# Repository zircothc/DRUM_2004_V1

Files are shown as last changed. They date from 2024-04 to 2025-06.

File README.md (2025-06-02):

# DRUM_2024_V1

ESP32 DRUM SYNTH MACHINE

This is my DRUM SYNTH LOFI MACHINE.



# Synth engine:

- Wavetable synthesizer based on DZL Arduino library ["The Synth"](https://github.com/dzlonline/the_synth)
- 16 sound polyphony
- Sound parameters: Table, Length, Envelope, Pitch, Modulation, + Volume, Pan and Filter.
- Filter (LowPassFilter) comes from [Mozzi Library](https://github.com/sensorium/Mozzi)

SEQUENCER:

- 16 step/pattern editor and random generators (pattern, sound parameters and notes)

# Hardware:

- Lolin S2 Mini (ESP32 S2)
- PCM5102A I2s dac
- 24 push buttons (8x3)
- Rotary encoder
- OLED display I2c
- 32 LED WS2812B

# Software:

IDE:
Arduino `1.8.19` 
Arduino `2.3.2`

Boards:
Expressif Systems `2.0.16` (Tested fine up to `2.0.17`)

Board: Lolin S2 Mini

Necessary Libraries:

- Sequencer Timer - [uClock](https://github.com/midilab/uClock)
- RGB Leds - [Adafruit Neopixel](https://github.com/adafruit/Adafruit_NeoPixel)
- OLED - [u8g2](https://github.com/olikraus/u8g2)
- Button input - [Keypad](https://github.com/Chris--A/Keypad)

# Notes:

Schematics uploaded.

STL 3D model uploaded.

Cheat sheet style PDF uploaded.

Join solder pads near SCK pin on PCM5102A module.

**Update**: 

- Solder pads on the back of PCM5102A module ([more info](https://github.com/pschatzmann/ESP32-A2DP/wiki/External-DAC#pcm5102-dac))
  
  - H1L: FLT - Low
  
  - H2L: DEMP - Low
  
  - H3L: XSMT - High
  
  - H4L: FMT - Low

Video demo of the prototype:

(https://www.youtube.com/watch?v=rXl1gpWJp-g)

Prototype:


# PCB, PROJECT & FINAL LOOK:

https://oshwlab.com/zircothc/esp32-drum-synth-lofi-machine

https://easyeda.com/editor#project_id=08f629c08b18444ca16accbb2242c0fb

PCB
pcb por ambas partes

PARTS MOUNTED
soldado
soldado por detras

SIZE: FINAL BUILD vs PROTOTYPE
SIZE

TWO MACHINES IN SYNC
sync

ALTERNATIVE CASE/ENCLOSURE




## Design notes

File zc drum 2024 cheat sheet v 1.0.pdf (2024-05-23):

# ZC DRUM 2024 cheat sheet v 1.0

### 16 Pads

| 0 | 1 | 2 | 3 | 4 | 5 | 6 | 7
Sound parameters | Wave | Envelope | Length | Pitch | Modulation | Volume | Pan | Filter | SHIFT (Rotary switch)
8 | 9 | 10 | 11 | 12 | 13 | 14 | 15
Misc parameters | BPM | Master
| Volume | Transport | Master Filter | Octave | Pattern (song
mode)* | Sync Mode | SHIFT (Rotary switch)

Modes / Functions

16 | 17 | 18 | 19 | 20 | 21 | 22 | 23
Pad | Random
| pattern
Load patterns Save patterns | Mute | Piano | Play | Song mode
Select | Random
sound | Load sounds Save sounds | Solo
Write | Random notes Load patterns
| | & sounds | Save patterns
| | | & sounds | Melodic
| | | | Clear
| | | | First step
| | | | Last step
| | | | Cancel Mutes
| | | | & Solos | | Record | Select last
pattern (song) | SHIFT (Rotary switch)
| Pad Play sound 0-15
Select Select sound
| Write Write mode
Random pattern random steps with random pitch at melodic tracks Random sound random parameters
Random note change pitch of steps marked ON at melodic tracks Load patterns (tracks) Load only patterns
Load sounds Load only sounds
Load pattern & sounds Load both
Save patterns (tracks) Save all patterns into a slot 0-15 Save sounds Save all sounds into a slot 0-15 Save patterns & sounds Save both
| Mute Mute track
| Solo Solo track
Melodic melodic plays saved pitch on each step and no melodic plays parameter pitch
| Clear Clear pattern
Fist step Select first step
Last step Select last step
Piano Sets pads as 16 piano keys
Play Set sequencer ON or OFF
Song mode Plays patterns asigned into a song

* Pattern song mode Rotary selects the pattern slot of a song. Press a pad to set the pattern into the slot

## OLED

Sound
selected | | S X
Selected
sound
parameter

### XXX

Value | | X
Pattern | | P X
Sound palette | | S X
Mode | | Xxxxxx

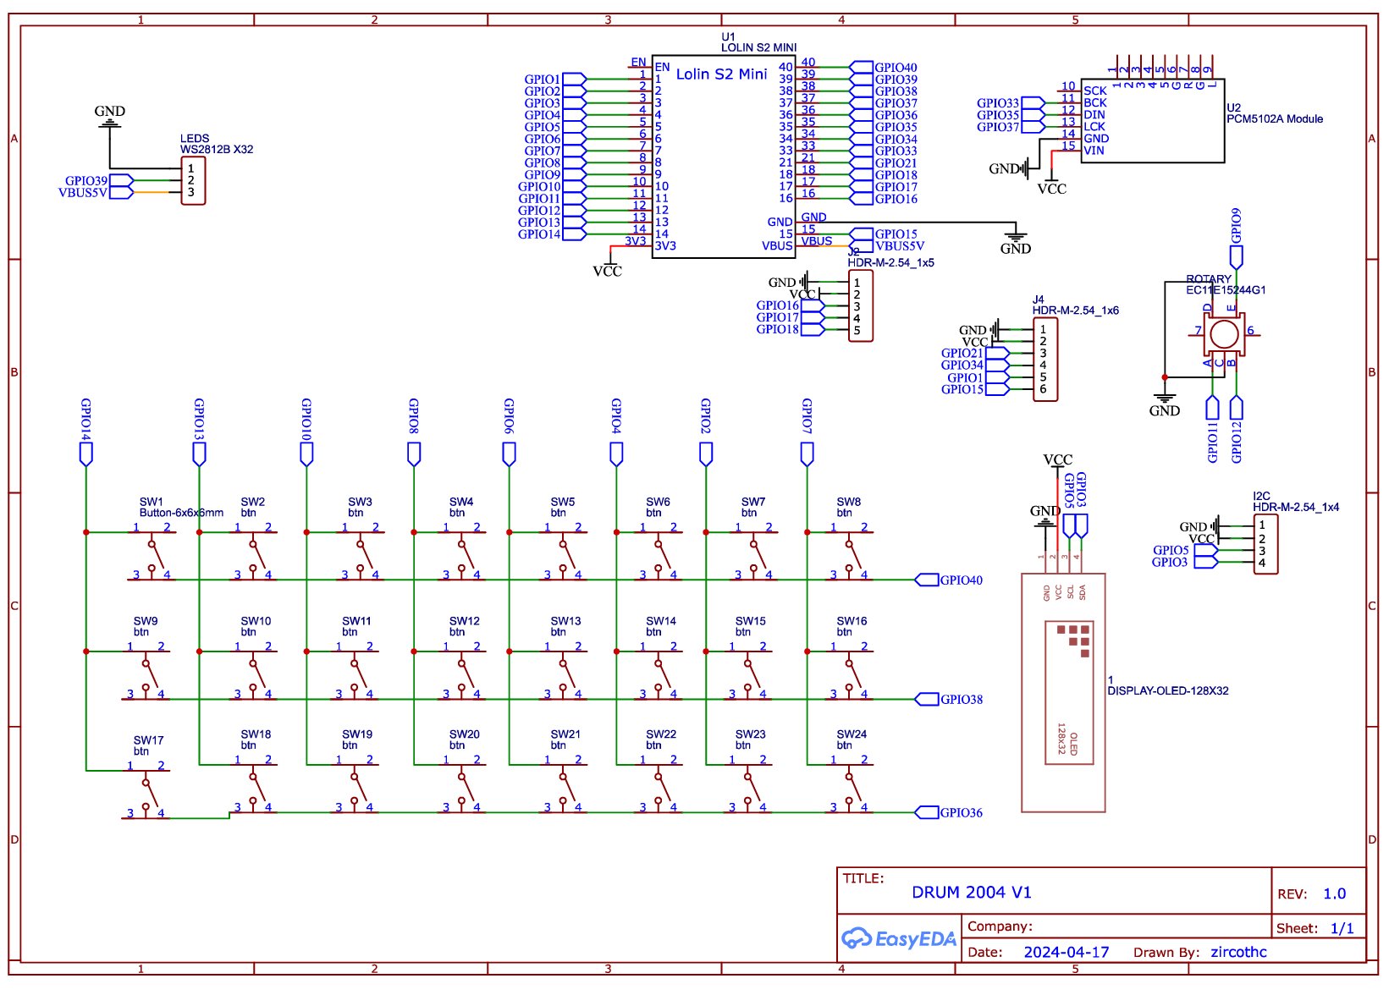
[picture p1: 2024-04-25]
SCHEMATICS.png

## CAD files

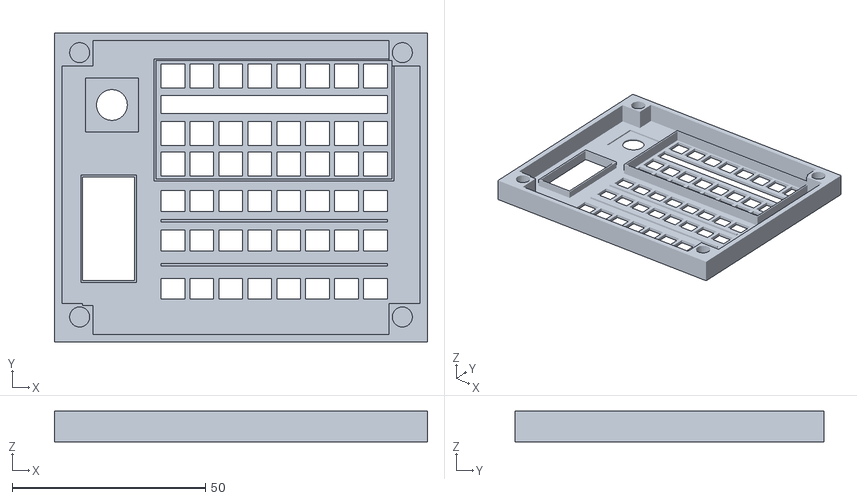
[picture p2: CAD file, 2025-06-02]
alt_mini_drum.stl
96.5 x 80.0 x 8.00

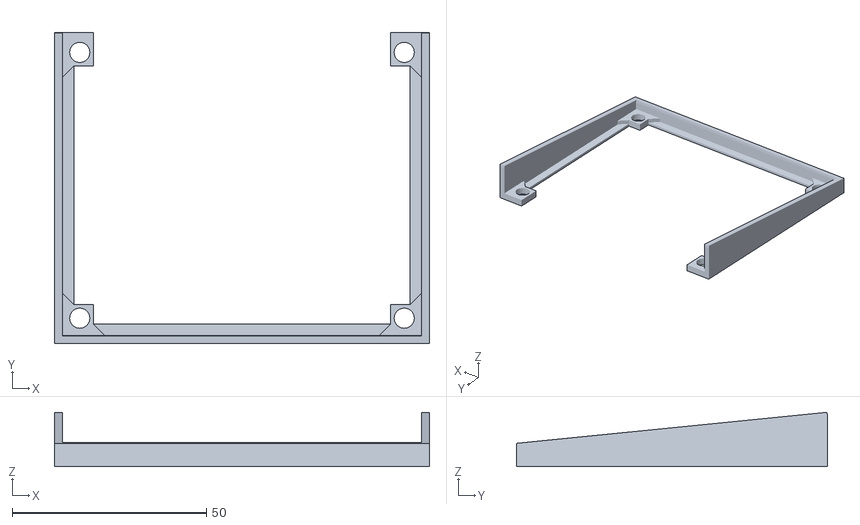
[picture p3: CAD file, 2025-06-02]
alt_inferior_mini_drum.stl
96.5 x 80.0 x 14.0

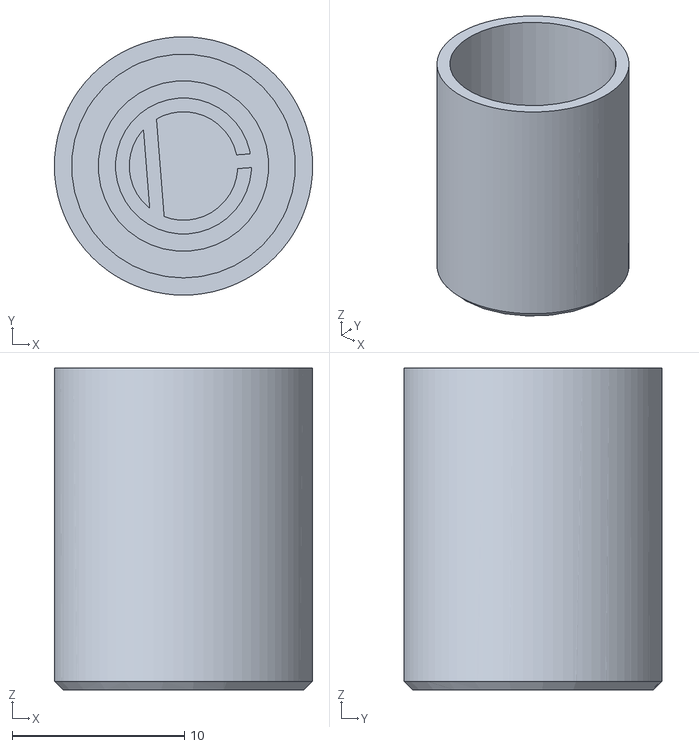
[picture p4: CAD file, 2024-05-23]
rotary_cap.stl
15.0 x 15.0 x 18.7

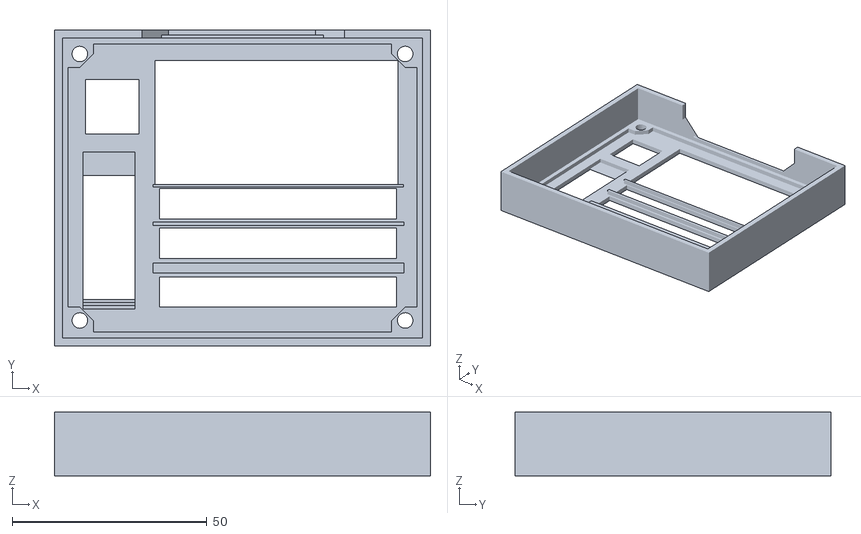
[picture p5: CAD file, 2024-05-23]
mini_drum_esp32s2.stl
96.5 x 81.0 x 16.4

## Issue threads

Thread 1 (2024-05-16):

Case STL

porkcube, 2024-05-16:
Can you add the .STL for the case please?

zircothc, 2024-05-23:
Hello.
I've uploaded STL file

;)

porkcube, 2024-05-23:
thank you!!

Closed 2024-05-23.

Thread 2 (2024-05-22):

EasyEDA schematics & HDR connections

ivosak, 2024-05-22:
Hello,

Please can you share also EasyEDA project link so we could copy PCB and order it :-)

Than I would like to ask for what are connectors **J2, J4 & I2C** for? What should be connected to them?

Thank you a lot!

zircothc, 2024-05-23:
Hi.

https://oshwlab.com/zircothc/esp32-drum-synth-lofi-machine
https://easyeda.com/editor#project_id=08f629c08b18444ca16accbb2242c0fb

I forgot to print labels for that pins. It is my second ordered PCB, excuse me ;)
These are free pins, not used, so you can attach more buttons, or add MIDI serial.
Communication isthe main porpouse.
The square marked pin at PCB is GND. Next is 3.3v, and the free pins.
Also I2c pins to use I2c devices :)
I have a pair of I2c modules I build with lots of rotaries but not so much time to play with it :(
I'm using J4 for serial to get a poor but simple sync system I'm testing now.

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

ivosak, 2024-05-23:
Thank you a lot!

Closed 2024-05-24.

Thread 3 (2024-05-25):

Compile error

ivosak, 2024-05-25:
Hello,
I just downloaded your project and not able to compile.
Any Idea?

[Compile-error.txt](https://github.com/zircothc/DRUM_2004_V1/files/15445115/Compile-error.txt)

Thank you
Ivo

zircothc, 2024-05-25:
Hi.
Your esp32 board version is 2.0.16.
Mine is 2.0.14.
I will test It.
Thanks.

porkcube, 2024-05-26:
I got the same with Arduino IDE `2.3.2`, using `1.8.19` as called out in the README worked fine.

ivosak, 2024-05-26:
mea culpa, mea maxima culpa
after reinstalling Aruduino and board, it works fine.

I needed to install also library **_Keypad.h_**, I guess it is this one: [https://github.com/Chris--A/Keypad](https://github.com/Chris--A/Keypad)
Correct?

porkcube, 2024-05-27:
Yeah that's that one I have installed in both 1.8.19 and should work.

ivosak, 2024-05-27:
great, thanks.
Waiting for Lolin S2 Mini (ESP32 S2) arrival and PCB and try it. Looking forward for new toy :)
Thank you for help!
Ivo

Closed 2024-05-27.

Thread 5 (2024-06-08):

WS2812B 4x4 orientation

ivosak, 2024-06-08:
Hi,
I have that created, it is amazing!
Please, can you share how did you placed that _2 WS2812B 4x4 matrix_es ?
Per my calculations there are 32 possible possitions how to place them and I picked one of incorrect one :-)
I mean how they are rotated, which is 1st, which 2nd ...

Thanks a lot!

ivosak, 2024-06-08:
Uploading 20240608_093142.mp41717832056369.mp4…

ivosak, 2024-06-08:
https://github.com/zircothc/DRUM_2004_V1/assets/36717650/4f99d9ab-dc25-4562-8e81-a0a9ce5488d7

zircothc, 2024-06-08:
Hello.
When I was taking a photo to my modules to show you how I did it... I open a new bag with modules I remember I bought two weeks ago and they are the same as you got. Capacitors are placed horizontal instead of vertical. Also "WCMU-2812B-16" text has dissapeared.
Well, I've just tested and LED layout it is very different. Older are a ziag-zag and newers are not.
So we have to do something at code. Its very easy, only we need to change the values of **real_led[32]** array.

At neopixel configuration you can see:

```
// Set more friendly led numbers
// 0 to 15 as 16 step, 16 sounds,... and 16 to 23 as selected modes
const byte real_led[32]={ 8, 9,10,11,24,25,26,27,15,14,13,12,31,30,29,28,
                          0, 1, 2, 3,16,17,18,19, 7, 6, 5, 4,23,22,21,20};

```
Change with:
```
const byte real_led[32]={ 4, 5, 6, 7,20,21,22,23, 0, 1, 2, 3,16,17,18,19,
                          12,13,14,15,28,29,31,31, 8, 9, 10,11,24,25,26,27};
```
I didn't test it, only "simple" neopixel example to test layout.

Also, in your video you soldered leds to vbus and gnd pins on esp32 but there are pins to do that marked as "LED" at PCB
Orientation is as you can see here:
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

Hope it helps.

ivosak, 2024-06-08:
Thanks for code update!
I used pins dedicated for led, only used vbus and gnd for external power (batteries), so can run it without power supply :-)

Once check new code, will close this ticket.
Thank you a lot for your care!

ivosak, 2024-06-08:
BTW I think there is small err in your updated code - you have there 31 twice...

zircothc, 2024-06-08:
Hi. Sorry.
...29,30,31,8,...

ivosak, 2024-06-08:
This helps, and now I know, what I am clicking on :-)
Thank you!

Closed 2024-06-08.

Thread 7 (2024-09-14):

Error compiling to enable midi

SKALOVSK, 2024-09-14:
**
Good evening, I'm trying to activate midi in the code but every time I compile it gives me the error below:
Without activating midi I can compile it normally

Arduino: 1.8.19 (Windows 10), Placa:"LOLIN S2 Mini, Enabled, Disabled, Disabled, Default 4MB with spiffs (1.2MB APP/1.5MB SPIFFS), None, Disabled"

C:\Users\user\Documents\Arduino\libraries\Adafruit_TinyUSB_Library\src\device\usbd.c:120:10: error: 'usbd_class_driver_t' {aka 'const struct <anonymous>'} has no member named 'name'

         .name             = DRIVER_NAME("CDC"),

          ^~~~

C:\Users\user\Documents\Arduino\libraries\Adafruit_TinyUSB_Library\src\device\usbd.c:122:10: error: 'usbd_class_driver_t' {aka 'const struct <anonymous>'} has no member named 'deinit'; did you mean 'init'?

         .deinit           = cdcd_deinit,

          ^~~~~~

          init

C:\Users\user\Documents\Arduino\libraries\Adafruit_TinyUSB_Library\src\device\usbd.c:122:29: error: 'cdcd_deinit' undeclared here (not in a function); did you mean 'dcd_deinit'?

         .deinit           = cdcd_deinit,

                             ^~~~~~~~~~~

                             dcd_deinit

C:\Users\user\Documents\Arduino\libraries\Adafruit_TinyUSB_Library\src\device\usbd.c:133:10: error: 'usbd_class_driver_t' {aka 'const struct <anonymous>'} has no member named 'name'

         .name             = DRIVER_NAME("MSC"),

          ^~~~

C:\Users\user\Documents\Arduino\libraries\Adafruit_TinyUSB_Library\src\device\usbd.c:135:10: error: 'usbd_class_driver_t' {aka 'const struct <anonymous>'} has no member named 'deinit'; did you mean 'init'?

         .deinit           = NULL,

          ^~~~~~

          init

C:\Users\user\Documents\Arduino\libraries\Adafruit_TinyUSB_Library\src\device\usbd.c:146:10: error: 'usbd_class_driver_t' {aka 'const struct <anonymous>'} has no member named 'name'

         .name             = DRIVER_NAME("HID"),

          ^~~~

C:\Users\user\Documents\Arduino\libraries\Adafruit_TinyUSB_Library\src\device\usbd.c:148:10: error: 'usbd_class_driver_t' {aka 'const struct <anonymous>'} has no member named 'deinit'; did you mean 'init'?

         .deinit           = hidd_deinit,

          ^~~~~~

          init

C:\Users\user\Documents\Arduino\libraries\Adafruit_TinyUSB_Library\src\device\usbd.c:148:29: error: 'hidd_deinit' undeclared here (not in a function); did you mean 'hidd_init'?

         .deinit           = hidd_deinit,

                             ^~~~~~~~~~~

                             hidd_init

C:\Users\user\Documents\Arduino\libraries\Adafruit_TinyUSB_Library\src\device\usbd.c:172:10: error: 'usbd_class_driver_t' {aka 'const struct <anonymous>'} has no member named 'name'

         .name             = DRIVER_NAME("VIDEO"),

          ^~~~

C:\Users\user\Documents\Arduino\libraries\Adafruit_TinyUSB_Library\src\device\usbd.c:174:10: error: 'usbd_class_driver_t' {aka 'const struct <anonymous>'} has no member named 'deinit'; did you mean 'init'?

         .deinit           = videod_deinit,

          ^~~~~~

          init

C:\Users\user\Documents\Arduino\libraries\Adafruit_TinyUSB_Library\src\device\usbd.c:174:29: error: 'videod_deinit' undeclared here (not in a function); did you mean 'videod_init'?

         .deinit           = videod_deinit,

                             ^~~~~~~~~~~~~

                             videod_init

C:\Users\user\Documents\Arduino\libraries\Adafruit_TinyUSB_Library\src\device\usbd.c:185:10: error: 'usbd_class_driver_t' {aka 'const struct <anonymous>'} has no member named 'name'

         .name             = DRIVER_NAME("MIDI"),

          ^~~~

C:\Users\user\Documents\Arduino\libraries\Adafruit_TinyUSB_Library\src\device\usbd.c:187:10: error: 'usbd_class_driver_t' {aka 'const struct <anonymous>'} has no member named 'deinit'; did you mean 'init'?

         .deinit           = midid_deinit,

          ^~~~~~

          init

C:\Users\user\Documents\Arduino\libraries\Adafruit_TinyUSB_Library\src\device\usbd.c:187:29: error: 'midid_deinit' undeclared here (not in a function); did you mean 'midid_init'?

         .deinit           = midid_deinit,

                             ^~~~~~~~~~~~

                             midid_init

C:\Users\user\Documents\Arduino\libraries\Adafruit_TinyUSB_Library\src\device\usbd.c:198:10: error: 'usbd_class_driver_t' {aka 'const struct <anonymous>'} has no member named 'name'

         .name             = DRIVER_NAME("VENDOR"),

          ^~~~

C:\Users\user\Documents\Arduino\libraries\Adafruit_TinyUSB_Library\src\device\usbd.c:200:10: error: 'usbd_class_driver_t' {aka 'const struct <anonymous>'} has no member named 'deinit'; did you mean 'init'?

         .deinit           = vendord_deinit,

          ^~~~~~

          init

C:\Users\user\Documents\Arduino\libraries\Adafruit_TinyUSB_Library\src\device\usbd.c:200:29: error: 'vendord_deinit' undeclared here (not in a function); did you mean 'vendord_init'?

         .deinit           = vendord_deinit,

                             ^~~~~~~~~~~~~~

                             vendord_init

C:\Users\user\Documents\Arduino\libraries\Adafruit_TinyUSB_Library\src\device\usbd.c:224:10: error: 'usbd_class_driver_t' {aka 'const struct <anonymous>'} has no member named 'name'

         .name             = DRIVER_NAME("DFU-RUNTIME"),

          ^~~~

C:\Users\user\Documents\Arduino\libraries\Adafruit_TinyUSB_Library\src\device\usbd.c:226:10: error: 'usbd_class_driver_t' {aka 'const struct <anonymous>'} has no member named 'deinit'; did you mean 'init'?

         .deinit           = dfu_rtd_deinit,

          ^~~~~~

          init

C:\Users\user\Documents\Arduino\libraries\Adafruit_TinyUSB_Library\src\device\usbd.c:226:29: error: 'dfu_rtd_deinit' undeclared here (not in a function); did you mean 'dfu_rtd_init'?

         .deinit           = dfu_rtd_deinit,

                             ^~~~~~~~~~~~~~

                             dfu_rtd_init

C:\Users\user\Documents\Arduino\libraries\Adafruit_TinyUSB_Library\src\device\usbd.c:237:10: error: 'usbd_class_driver_t' {aka 'const struct <anonymous>'} has no member named 'name'

         .name             = DRIVER_NAME("DFU"),

          ^~~~

C:\Users\user\Documents\Arduino\libraries\Adafruit_TinyUSB_Library\src\device\usbd.c:239:10: error: 'usbd_class_driver_t' {aka 'const struct <anonymous>'} has no member named 'deinit'; did you mean 'init'?

         .deinit           = dfu_moded_deinit,

          ^~~~~~

          init

C:\Users\user\Documents\Arduino\libraries\Adafruit_TinyUSB_Library\src\device\usbd.c:239:29: error: 'dfu_moded_deinit' undeclared here (not in a function); did you mean 'dfu_moded_init'?

         .deinit           = dfu_moded_deinit,

                             ^~~~~~~~~~~~~~~~

                             dfu_moded_init

C:\Users\user\Documents\Arduino\libraries\Adafruit_TinyUSB_Library\src\device\usbd.c: In function 'tud_sof_cb_enable':

C:\Users\user\Documents\Arduino\libraries\Adafruit_TinyUSB_Library\src\device\usbd.c:405:33: error: 'SOF_CONSUMER_USER' undeclared (first use in this function)

   usbd_sof_enable(_usbd_rhport, SOF_CONSUMER_USER, en);

                                 ^~~~~~~~~~~~~~~~~

C:\Users\user\Documents\Arduino\libraries\Adafruit_TinyUSB_Library\src\device\usbd.c:405:33: note: each undeclared identifier is reported only once for each function it appears in

C:\Users\user\Documents\Arduino\libraries\Adafruit_TinyUSB_Library\src\device\usbd.c:405:3: error: too many arguments to function 'usbd_sof_enable'

   usbd_sof_enable(_usbd_rhport, SOF_CONSUMER_USER, en);

   ^~~~~~~~~~~~~~~

In file included from C:\Users\user\Documents\Arduino\libraries\Adafruit_TinyUSB_Library\src\device\usbd.c:41:

C:\Users\user\AppData\Local\Arduino15\packages\esp32\hardware\esp32\2.0.17/tools/sdk/esp32s2/include/arduino_tinyusb/tinyusb/src/device/usbd_pvt.h:113:6: note: declared here

 void usbd_sof_enable(uint8_t rhport, bool en);

      ^~~~~~~~~~~~~~~

C:\Users\user\Documents\Arduino\libraries\Adafruit_TinyUSB_Library\src\device\usbd.c: In function 'tud_deinit':

C:\Users\user\Documents\Arduino\libraries\Adafruit_TinyUSB_Library\src\device\usbd.c:473:26: error: 'usbd_class_driver_t' {aka 'const struct <anonymous>'} has no member named 'deinit'; did you mean 'init'?

     if(driver && driver->deinit) {

                          ^~~~~~

                          init

C:\Users\user\Documents\Arduino\libraries\Adafruit_TinyUSB_Library\src\device\usbd.c:475:15: error: 'usbd_class_driver_t' {aka 'const struct <anonymous>'} has no member named 'deinit'; did you mean 'init'?

       driver->deinit();

               ^~~~~~

               init

C:\Users\user\Documents\Arduino\libraries\Adafruit_TinyUSB_Library\src\device\usbd.c:475:7: error: called object is not a function or function pointer

       driver->deinit();

       ^~~~~~

C:\Users\user\Documents\Arduino\libraries\Adafruit_TinyUSB_Library\src\device\usbd.c: In function 'tud_task_ext':

C:\Users\user\Documents\Arduino\libraries\Adafruit_TinyUSB_Library\src\device\usbd.c:638:49: error: 'SOF_CONSUMER_USER' undeclared (first use in this function)

         if (tu_bit_test(_usbd_dev.sof_consumer, SOF_CONSUMER_USER)) {

                                                 ^~~~~~~~~~~~~~~~~

C:\Users\user\Documents\Arduino\libraries\Adafruit_TinyUSB_Library\src\device\usbd.c: In function 'dcd_event_handler':

C:\Users\user\Documents\Arduino\libraries\Adafruit_TinyUSB_Library\src\device\usbd.c:1200:47: error: 'SOF_CONSUMER_USER' undeclared (first use in this function)

       if (tu_bit_test(_usbd_dev.sof_consumer, SOF_CONSUMER_USER)) {

                                               ^~~~~~~~~~~~~~~~~

C:\Users\user\Documents\Arduino\libraries\Adafruit_TinyUSB_Library\src\device\usbd.c: At top level:

C:\Users\user\Documents\Arduino\libraries\Adafruit_TinyUSB_Library\src\device\usbd.c:1440:38: error: unknown type name 'sof_consumer_t'

 void usbd_sof_enable(uint8_t rhport, sof_consumer_t consumer, bool en) {

                                      ^~~~~~~~~~~~~~

exit status 1

Erro compilando para a placa LOLIN S2 Mini

zircothc, 2024-09-15:
Hi
I did some work to get USB midi but audio got a lot of noise that come from PC USB so I did not try it anymore.
I will run some test.
;)

SKALOVSK, 2024-09-15:
Cool, I managed to activate Midi using the adafruit 3.1.3 library, I'll do some more grounding tests here to reduce the noise.

SKALOVSK, 2024-09-20:
I managed to activate Midi and talk to Ableton, but it has a lot of lag, I'm trying to find out the reason, but apparently it sends data for no reason...

GitCiock, 2025-03-16:
> I managed to activate Midi and talk to Ableton, but it has a lot of lag, I'm trying to find out the reason, but apparently it sends data for no reason...

Hi, have you done some developments on the midi project? Could you share your code and if needed some info on how to run it? Thank you very much!

zircothc, 2025-03-16:
Hi.
I'm doing a lot of projects in my not much free time and USB MIDI IN is not one of them. Sorry. As I said when you power a ESP32 with my PC a got a lot of audio noise Also there is a lot of lag as you wrote so I will not work on it anymore. I think is the way ESP32 boards are designed. May be with a development board with a good filtered power converter...but I dont know.
RP2040 on the other hand is perfect to be powerd by USB while managing audio. You can try this: https://www.youtube.com/watch?v=vcXr4dKAKsk&t=6s&ab_channel=RyoIshigaki
It is amazing. I build some of them. Ryo make awesome projects.

I'm triying USB MIDI out with ESP32 S3. I read it at a Japanesse blog and I think it is possible.
With ESP32 S2 is very easy to do MIDI out over USB but MIDI IN is not the same.
If you want to send MIDI to your machine you need to use serial in with optocoupler. It runs quite well.
;)

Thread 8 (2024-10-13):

Error compiling uClock library not correct ?

SurvivalHacking, 2024-10-13:
Hi, when I try to compile I got some error not in code but in library usage.
There are some updated or different uClock library to be used ?

FQBN: esp32:esp32:lolin_s2_mini
Utilizzo della scheda 'lolin_s2_mini' dalla piattaforma nella cartella: /Users/thor/Library/Arduino15/packages/esp32/hardware/esp32/3.0.5
Utilizzo del core 'esp32' dalla piattaforma nella cartella: /Users/thor/Library/Arduino15/packages/esp32/hardware/esp32/3.0.5

   50 |     _uclockTimer = timerBegin(TIMER_ID, 80, true);
      |                    ~~~~~~~~~~^~~~~~~~~~~~~~~~~~~~
In file included from /Users/thor/Library/Arduino15/packages/esp32/hardware/esp32/3.0.5/cores/esp32/esp32-hal.h:84,
                 from /Users/thor/Library/Arduino15/packages/esp32/hardware/esp32/3.0.5/cores/esp32/Arduino.h:36,
                 from /Users/thor/Documents/Arduino/libraries/uClock/src/uClock.h:32,
                 from /Users/thor/Documents/Arduino/libraries/uClock/src/uClock.cpp:28:
/Users/thor/Library/Arduino15/packages/esp32/hardware/esp32/3.0.5/cores/esp32/esp32-hal-timer.h:35:13: note: declared here
   35 | hw_timer_t *timerBegin(uint32_t frequency);
      |             ^~~~~~~~~~
/Users/thor/Documents/Arduino/libraries/uClock/src/platforms/esp32.h:53:25: error: too many arguments to function 'void timerAttachInterrupt(hw_timer_t*, void (*)())'
   53 |     timerAttachInterrupt(_uclockTimer, &handlerISR, false);
      |     ~~~~~~~~~~~~~~~~~~~~^~~~~~~~~~~~~~~~~~~~~~~~~~~~~~~~~~
/Users/thor/Library/Arduino15/packages/esp32/hardware/esp32/3.0.5/cores/esp32/esp32-hal-timer.h:50:6: note: declared here
   50 | void timerAttachInterrupt(hw_timer_t *timer, void (*userFunc)(void));
      |      ^~~~~~~~~~~~~~~~~~~~
/Users/thor/Documents/Arduino/libraries/uClock/src/platforms/esp32.h:56:5: error: 'timerAlarmWrite' was not declared in this scope; did you mean 'timerWrite'?
   56 |     timerAlarmWrite(_uclockTimer, init_clock, true);
      |     ^~~~~~~~~~~~~~~
      |     timerWrite
/Users/thor/Documents/Arduino/libraries/uClock/src/platforms/esp32.h:59:5: error: 'timerAlarmEnable' was not declared in this scope; did you mean 'timerAlarm'?
   59 |     timerAlarmEnable(_uclockTimer);
      |     ^~~~~~~~~~~~~~~~
      |     timerAlarm
/Users/thor/Documents/Arduino/libraries/uClock/src/platforms/esp32.h: In function 'void setTimer(uint32_t)':
/Users/thor/Documents/Arduino/libraries/uClock/src/platforms/esp32.h:64:5: error: 'timerAlarmWrite' was not declared in this scope; did you mean 'timerWrite'?
   64 |     timerAlarmWrite(_uclockTimer, us_interval, true);
      |     ^~~~~~~~~~~~~~~
      |     timerWrite

Uso la libreria FS alla versione 3.0.5 nella cartella: /Users/thor/Library/Arduino15/packages/esp32/hardware/esp32/3.0.5/libraries/FS
Uso la libreria SPIFFS alla versione 3.0.5 nella cartella: /Users/thor/Library/Arduino15/packages/esp32/hardware/esp32/3.0.5/libraries/SPIFFS
Uso la libreria U8g2 alla versione 2.35.30 nella cartella: /Users/thor/Documents/Arduino/libraries/U8g2
Uso la libreria Wire alla versione 3.0.5 nella cartella: /Users/thor/Library/Arduino15/packages/esp32/hardware/esp32/3.0.5/libraries/Wire
Uso la libreria Adafruit NeoPixel alla versione 1.12.3 nella cartella: /Users/thor/Documents/Arduino/libraries/Adafruit_NeoPixel
Uso la libreria uClock alla versione 2.1.0 nella cartella: /Users/thor/Documents/Arduino/libraries/uClock
Uso la libreria Keypad alla versione 3.1.1 nella cartella: /Users/thor/Documents/Arduino/libraries/Keypad
Uso la libreria SPI alla versione 3.0.5 nella cartella: /Users/thor/Library/Arduino15/packages/esp32/hardware/esp32/3.0.5/libraries/SPI
exit status 1

Compilation error: exit status 1

SurvivalHacking, 2024-10-13:
Ok, I',m a donkey.
It is because I updated at the latest ESP32 subsystem 3.0.5 and it is not compatible.
I installed 2.0.18 and compile without problems

zircothc, 2024-10-13:
Uclock library needs to be updated

Closed 2024-10-13.

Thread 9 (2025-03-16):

Adding sampled sound (.WAV files)

GitCiock, 2025-03-16:
Hi, fist of all I wanted to thank you because i made the drum machine, and I really love it, you did a really good job!
Then i want to ask you if you have any idea on how to implement sampled sound like .WAV Files.
My idea was to implement a second Bank (or set) of sound loaded into the internal memory, and use it as the sound made by the synthesizer, so maybe changing wave form, envelop, pitch, filter, and obviously loaded into the sequencer (if this is not possible, simply play the wav files into the sequencer).
If you have any ideas or maybe some prototipe code or some documentation on how to implement it,  it would really help me a lot.
Thank you again for your fantastic work on this project!

zircothc, 2025-03-16:
Hi.
I'm very happy you build it.

What you want... I did it:)
This will be my next "project".
At this moment sounds ares stored on flash; wav files are converted to .h files.
It runs quite well. Now I stored about 50 samples into 3MB app partition. I'm trying to use 15MB app partition and increase number of samples, but its a nightmare.

But I also coded some functions to read SD and store samples into PSRAM but I need to develop it a bit more.
Now I'm coding two sound engines at the same machine, lofi synth and hifi sampler but. It will be a very fun grooveboox.

But I have no much free time to pack it all, record video, upload code,...
Please wait a few days (I wish) :)

Meanwhile If you want to read some code that did you want, go to my old project based on ESP8266. Audio I2s is not the same but the way I read samples and mix them togheter is almost the same. https://zircothc.wordpress.com/2019/04/11/caja-de-ritmos-con-esp8266-v2/
;)

GitCiock, 2025-03-16:
That sounds awesome, I will wait your next project, meanwhile i try to read the code.
Thank you very much! :)

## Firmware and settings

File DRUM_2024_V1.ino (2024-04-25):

////////////////////////////
// DRUM 2024              //
////////////////////////////
// ZCARLOS 2024
// Based on DZL's library "the_synth"
// Ported to ESP32 internal DACs but...
// DAC outs sounds very noisy
// Instead of modify the library I cut it into functions to try to port to pcm5102a i2s DAC out, DONE :)
// Extended tables up to 14 and voices up to 16
// Mixer section (L&R) per voice
// Filter per voice and master filter (from Mozzi library)


// includes
#include <Arduino.h>
////////////////////////////// SPIFFS
#include <FS.h>
#include <SPIFFS.h>

////////////////////////////// OLED
#include <U8g2lib.h>
#include <Wire.h>
////////////////////////////// SYNTH
#define SAMPLE_RATE 22050
#include "driver/i2s.h"
#include "synthESP32LowPassFilter_E.h" // filter
#include "tablesESP32_E.h"


////////////////////////////// LEDS
#include <Adafruit_NeoPixel.h>
////////////////////////////// TIMER SEQ 
#include <uClock.h>
////////////////////////////// KEYPAD
#include <Keypad.h>
////////////////////////////// MIDI USB
//#include <Adafruit_TinyUSB.h>
//#include <MIDI.h>


////////////////////////////////////////////////////////////////////////////////////////////
////////////////////////////////////////////////////////////////////////////////////////////



////////////////////////////// OLED
U8G2_SSD1306_128X32_UNIVISION_F_HW_I2C u8g2(U8G2_R3, /* reset=*/ U8X8_PIN_NONE, /* clock=*/ 5, /* data=*/ 3);   // pin remapping with ESP8266 HW I2C

const String trot[18] = { "WAV", "ENV", "LEN", "PIT", "MOD", "VOL", "PAN", "FIL", "BPM","MVO","TRP","MFI","OCT","PSN","GP1","GD1","GP2","GD2"};
const String tmodeZ[20] = { "Pad", "Sel", "Write", "Mute", "Solo", "Clear","LoadP","LoadS","LoaPS","SaveP","SaveS","SavPS","RndS","RndP","First","Last","Melod","RndNo","Piano","Song"};

// modeZ types

//  0 - play pad sound
//  1 - select sound
//  2 - edit track, write
//  3 - mute
//  4 - solo
//  5 - clear

//  6 - load pattern
//  7 - load pattern
//  8 - load pattern and sound

//  9 - save pattern
// 10 - save sound
// 11 - save sound and pattern
 
// 12 - random sound
// 13 - random pattern
// 14 - first step
// 15 - last step
// 16 - set melodic (read pitch from pattern melodic instead of rotary value)
// 17 - random note
// 18 - piano
// 10 - song (edit song)

#define tPad    0
#define tSel    1
#define tWrite  2
#define tMute   3
#define tSolo   4
#define tClear  5
#define tLoadP  6
#define tLoadS  7
#define tLoaPS  8
#define tSaveP  9
#define tSaveS 10
#define tSavPS 11
#define tRndS  12
#define tRndP  13
#define tFirst 14
#define tLast  15
#define tMelod 16
#define tRndNo 17
#define tPiano 18
#define tSong  19

////////////////////////////// SYNTH

// SINE     0
// TRIANGLE 1
// SQUARE   2
// SAW      3
// RAMP     4
// NOISE    5
// PHASOR   6
// WN1      7
// WN2      8
// WN3      9
// WN4      10
// WN5      11
// WN6      12
// WN7      13
//
// ENVELOPE0 0
// ENVELOPE1 1
// ENVELOPE2 2
// ENVELOPE3 3


#define SAMPLE_RATE 22050

// i2s

#define I2S_BCK_PIN 33
#define I2S_WS_PIN 37
#define I2S_DATA_OUT_PIN 35

#define DMA_BUF_LEN     32          
#define DMA_NUM_BUF     2

static uint16_t out_buf[DMA_BUF_LEN * 2];

// Filters master (L&R) and 16 sounds
LowPassFilter lpfR;
LowPassFilter lpfL;

LowPassFilter lpf0;
LowPassFilter lpf1;
LowPassFilter lpf2;
LowPassFilter lpf3;
LowPassFilter lpf4;
LowPassFilter lpf5;
LowPassFilter lpf6;
LowPassFilter lpf7;
LowPassFilter lpf8;
LowPassFilter lpf9;
LowPassFilter lpf10;
LowPassFilter lpf11;
LowPassFilter lpf12;
LowPassFilter lpf13;
LowPassFilter lpf14;
LowPassFilter lpf15;

const int cutoff=255;
const int reso=511;

int vmeter=0;

static unsigned int PCW[16] = {0, 0, 0, 0,0 ,0 ,0 ,0,0, 0, 0, 0,0 ,0 ,0 ,0};      //-Wave phase accumolators
static unsigned int FTW[16] = {1000, 200, 300, 400, 1000, 200, 300, 400, 1000, 200, 300, 400, 1000, 200, 300, 400};           //-Wave frequency tuning words
static unsigned char AMP[16] = {255, 255, 255, 255, 255, 255, 255, 255, 255, 255, 255, 255, 255, 255, 255, 255};           //-Wave amplitudes [0-255]
static unsigned int PITCH[16] = {500, 500, 500, 500, 500, 500, 500, 500, 500, 500, 500, 500, 500, 500, 500, 500};          //-Voice pitch
static int MOD[16] = {64, 64, 64, 64, 64, 64, 64, 64, 64, 64, 64, 64, 64, 64, 64, 64};                      //-Voice envelope modulation [0-1023 512=no mod. <64 pitch down >64 pitch up]

static int VOL_R[16] = {10, 10, 10, 10, 10, 10, 10, 10, 10, 10, 10, 10, 10, 10, 10, 10}; 
static int VOL_L[16] = {10, 10, 10, 10, 10, 10, 10, 10, 10, 10, 10, 10, 10, 10, 10, 10};   
static int PAN[16] = {10, 10, 10, 10, 10, 10, 10, 10, 10, 10, 10, 10, 10, 10, 10, 10}; 
static int FILTER[16]= {127, 127, 127, 127, 127, 127, 127, 127, 127, 127, 127, 127, 127, 127, 127, 127};                  //-mozzi FILTERS  0-255

static unsigned int wavs[16];                                  //-Wave table selector [address of wave in memory]
static unsigned int envs[16];                                  //-Envelope selector [address of envelope in memory]
static unsigned int EPCW[16] = {0x8000, 0x8000, 0x8000, 0x8000, 0x8000, 0x8000, 0x8000, 0x8000, 0x8000, 0x8000, 0x8000, 0x8000, 0x8000, 0x8000, 0x8000, 0x8000}; //-Envelope phase accumulator
static unsigned int EFTW[16] = {10, 10, 10, 10, 10, 10, 10, 10, 10, 10, 10, 10, 10, 10, 10, 10};               //-Envelope speed tuning word
static unsigned int divider = 16;                             //-Sample rate decimator for envelope

static int mvol=10;
int master_vol=17;
int master_filter=0;
int octave=5;

////////////////////////////// LEDS
#define LED_PIN    39
#define LED_COUNT 32
Adafruit_NeoPixel strip(LED_COUNT, LED_PIN, NEO_GRB + NEO_KHZ800);
// Set more friendly led numbers
// 0 to 15 as 16 step, 16 sounds,... and 16 to 23 as selected modes
const byte real_led[32]={ 8, 9,10,11,24,25,26,27,15,14,13,12,31,30,29,28,
                          0, 1, 2, 3,16,17,18,19, 7, 6, 5, 4,23,22,21,20};
int counter_refresh=0;
const byte limit_counter_refresh=7;
boolean start_counter_refresh=false;

////////////////////////////// MIDI USB
//Adafruit_USBD_MIDI usb_midi;
//MIDI_CREATE_INSTANCE(Adafruit_USBD_MIDI, usb_midi, MIDI);


////////////////////////////// TIMER SEQ 
int bpm=120;
int stepInterval;
int microStep=0;
byte selected_pattern=0;
byte sstep=0;
byte selected_len=16;
boolean updateBPM=false;
uint16_t mutes=0;
uint16_t solos=0;
uint16_t pattern[16];
byte song[255];
int pattern_song_counter=-1;
byte last_pattern_song=255;
uint8_t  melodic[16][16];
//uint16_t isMelodic=B11111111<<8 | B00000000; // last 8 sounds are set to melodic
uint16_t isMelodic=B00000000<<8 | B00000000; // none set to melodic
byte firstStep=0;
byte lastStep=15;
byte newLastStep=15; 
byte selected_sound=0;
byte oldselected_sound=0;
byte selected_sndSet=0;
int transpose=0;
boolean load_flag=false;

////////////////////////////// ROTARY
void IRAM_ATTR i_ENCODERS();
const byte pinBR1=9;
const byte pinR1A=11;
const byte pinR1B=12;
byte ENC_PORT1=0;
int counter1=0;
int old_counter1=0;
boolean readencoders=false;
byte shiftR1=false;
byte RV;

// 8 sound parameters + bpm + master vol + transpose + master filter + octave + Pattern song selector +  4 Audino parameters
const int max_values[18]={13,3,127,127,127,31, 99,127,400,31, 1,127,10,255,511,127,511,255}; 
const int min_values[18]={ 0,0,  0,  0,  0, 0,-99,  0,  0, 0,-1,  0, 0,  0,0,0,0,0};

int ROTvalue[16][8]={ // init sound values
  { 0,2, 32, 35,29,7,-31,0}, // THIS IS VOICE #0
  { 5,1, 50,127,31,7,-31,0}, // THIS IS VOICE #1
  { 9,2, 25, 41,95,7,  0,0}, // ...
  { 0,0, 60, 64,30,7,  0,0},
  {13,2, 47, 44,82,7,  0,0},
  { 8,2, 42, 29,31,7,  0,0},
  { 0,0, 30, 54,64,7,  0,0},
  { 3,0, 25, 44,64,7,  0,0},
  
  { 0,2, 32, 25,29,7, 66,0},
  { 5,2, 50,107,31,7, 66,0},
  { 9,2, 25, 31,95,7,  0,0},
  { 0,0, 60, 54,30,7,  0,0},
  {13,2, 47, 54,82,7,  0,0},
  { 8,2, 42, 19,31,7,  0,0},
  { 0,0, 40, 44,64,7, 30,0},
  { 3,0, 80, 34,64,7,-30,0}
};

byte selected_rot=0;

////////////////////////////// KEYPAD

const byte ROWS = 8; //four rows
const byte COLS = 3; //three columns
char keys[ROWS][COLS] = {
  {'1','2','3'},
  {'4','5','6'},
  {'7','8','9'},
  {'*','0','#'},
  {'a','s','d'},
  {'z','x','c'},
  {'f','g','h'},
  {'v','b','n'}  
};
// need to confirm if this is the right order in the PCB version
byte rowPins[ROWS] = {14, 13, 10, 8,6,4,2,7}; //connect to the row pinouts of the keypad
byte colPins[COLS] = {40,38,36}; //connect to the column pinouts of the keypad
Keypad kpd = Keypad( makeKeymap(keys), rowPins, colPins, ROWS, COLS );
byte trigger_on[24];
byte nkey;

// Set more friendly key numbers
// 0 to 15 as 16 step, 16 sounds,... and 16 to 23 as selected modes
const byte real_key[24]={ 
 0, 8,16,
 1, 9,17,
 2,10,18,
 3,11,19,
 4,12,20,
 5,13,21,
 6,14,22,
 7,15,23
};

byte pad_touched=0;

////////////////////////////// MISC
byte modeZ=0;
byte last_modeZ=0;
byte last_sound=0;

boolean playing   = false;
boolean songing   = false; // switch to make load auto patterns++
boolean recording = false;
//boolean shifting  = false;

boolean clearPATTERN=false;
boolean clearSTEP=false;
boolean refreshPATTERN=true;
boolean refreshSTEP=false;
boolean refreshSTATUS=false;
boolean refreshMODES=true;
boolean refreshOLED=true;
boolean refreshPADTOUCHED=false;
boolean stepzero = false; // tool to reset the first step and last step the seq searchs for start/end point of the loop
#define MIDI_CLOCK 0xF8
#define MIDI_START 0xFA
#define MIDI_STOP  0xFC


////////////////////////////////////////////////////////////////////////////////////////////
////////////////////////////////////////////////////////////////////////////////////////////

void setSound(byte f){
  synthESP32_setWave(f,ROTvalue[f][0]);  
  synthESP32_setEnvelope(f,ROTvalue[f][1]);
  synthESP32_setLength(f,ROTvalue[f][2]);
  synthESP32_setPitch(f,ROTvalue[f][3]);
  synthESP32_setMod(f,ROTvalue[f][4]); 
  synthESP32_setVol(f,ROTvalue[f][5]);  
  synthESP32_setPan(f,ROTvalue[f][6]);  
  synthESP32_setFilter(f,ROTvalue[f][7]);  
}
void setRandomVoice(byte f){
  ROTvalue[f][0]=random(0, 14);
  ROTvalue[f][1]=random(0, 4);
  ROTvalue[f][2]=random(1, 60);
  ROTvalue[f][3]=random(0, 127);
  ROTvalue[f][4]=random(10,100);
  ROTvalue[f][5]=random(10,15);
  ROTvalue[f][6]=random(-99,99);
  ROTvalue[f][7]=random(0,60);
}
void setRandomPattern(byte f){
  byte veces=random(0,2);
  for (byte b = 0; b < 16; b++) {
    byte mybit=random(0,2);
    if (veces) {
      if (mybit) mybit=random(0,2); // Si es 1 hago otro random para que haya menos unos
    }
    bitWrite(pattern[f],b,mybit);
  } 
  setRandomPitch(f);
}

void setRandomPitch(byte f){
  // Tomo como referencia para el rango el valor del pot pitch actual
  uint8_t actual=ROTvalue[selected_sound][3];
  uint8_t limite;
  uint8_t prelimite=24;
  if (shiftR1) prelimite = 24;
  for (byte b = 0; b < 16; b++) {
     limite=actual+random(0,prelimite);
     melodic[f][b]=random(actual-(prelimite>>1),limite);
  }  
}

void setRandomNotes(byte f){
  setRandomPitch(f);
}
////////////////////////////////////////////////////////////////////////////////////////////
////////////////////////////////////////////////////////////////////////////////////////////
void onSync24Callback(uint32_t tick){

  
  // Lanzar cambio de step
  if (!(tick % (6))) tic(tick);
  // Limpiar patrón
  if ((tick % (6))==4) clearPATTERN=true;

  
}

void tic(uint32_t tick){
  
//  if (playing){
    //if (microStep==0){
      clearSTEP=true;
      for (int f = 0; f < 16; f++) { 
        if (!bitRead(mutes, f)) {
          if (solos == 0 || (solos > 0 && bitRead(solos, f))) {
            if (bitRead(pattern[f], sstep)) { // note on
              if (bitRead(isMelodic,f)){
                //synthESP32_setPitch(f,melodic[f][sstep]);

                  synthESP32_mTrigger(f,melodic[f][sstep]);                  

              } else {
                // reestablecer el pitch
                synthESP32_setPitch(f,ROTvalue[f][3]);                
                synthESP32_trigger(f);
              }
            } 
          }
        }
      }
  
      sstep++;
      // Comprobar step final
      if (sstep==(lastStep+1) || sstep==(newLastStep+1) || (stepzero) || sstep==16) {
        lastStep=newLastStep;
        stepzero=false;
        sstep=firstStep;
        //Serial.println("Toc");
        if (songing){
          load_flag=true; // inside loop I will load next pattern
        }
      }
      refreshSTEP=true;
      refreshPATTERN=true; 
//    }


    

}
////////////////////////////////////////////////////////////////////////////////////////////
////////////////////////////////////////////////////////////////////////////////////////////

void load_pattern(byte pat){
  
  // Leer pattren
  String nombreArchivoP = "/PAT" + String(pat);
  File archivoP = SPIFFS.open(nombreArchivoP, FILE_READ);   
  if (!archivoP) {
    Serial.println("Error al abrir el archivo para leer");
    return;
  }
  int fila = 0;
  while (archivoP.available()) {
    pattern[fila] = (archivoP.readStringUntil('\n')).toInt();
    //Serial.println(pattern[fila]);
    fila++;
  }
  archivoP.close();
  //Serial.println("-");


  // Leer melodic
  String nombreArchivoM = "/MED" + String(pat);
  File archivoM = SPIFFS.open(nombreArchivoM, FILE_READ);
  if (!archivoM) {
    Serial.println("Error al abrir el archivo para leer");
    return;
  }
  fila = 0;
  int columna = 0;  
  while (archivoM.available()) {
    melodic[fila][columna] = (archivoM.readStringUntil('\n')).toInt();
    columna++;
    if (columna == 16) {
      fila++;
      columna = 0;
    }
  }
  archivoM.close(); 

  
}

void load_sound(byte pat){
  
  // Leer sound
  String nombreArchivoS = "/SND" + String(pat);
  File archivoS = SPIFFS.open(nombreArchivoS, FILE_READ);
  if (!archivoS) {
    Serial.println("Error al abrir el archivo para leer");
    return;
  }
  int fila = 0;
  int columna = 0;  
  while (archivoS.available()) {
    ROTvalue[fila][columna] = (archivoS.readStringUntil('\n')).toInt();
    columna++;
    if (columna == 8) {
      // Set voices
      setSound(fila);
      fila++;
      columna = 0;
    }
  }
  archivoS.close(); 

}

void save_pattern(byte pat){
  
  // Guardar pattern
  String nombreArchivoP = "/PAT" + String(pat);
  File archivoP = SPIFFS.open(nombreArchivoP, FILE_WRITE);   
  if (!archivoP) {
    Serial.println("Error al abrir el archivo para escribir");
    return;
  }
  for (int i = 0; i < 16; i++) {
    archivoP.println(pattern[i]);
    //Serial.println(pattern[i]);
  }
  archivoP.close();
  //Serial.println("-");  

  // Guardar melodic
  String nombreArchivoM = "/MED" + String(pat);
  File archivoM = SPIFFS.open(nombreArchivoM, FILE_WRITE); 
  if (!archivoM) {
    Serial.println("Error al abrir el archivo para escribir");
    return;
  }
  for (int i = 0; i < 16; i++) {
    for (int j = 0; j < 16; j++) {
      archivoM.println(melodic[i][j]);
    }
  }
  archivoM.close();

  
}
void save_sound(byte pat){
  
  // Guardar sound
  String nombreArchivoS = "/SND" + String(pat);
  File archivoS = SPIFFS.open(nombreArchivoS, FILE_WRITE); 
  if (!archivoS) {
    Serial.println("Error al abrir el archivo para escribir");
    return;
  }
  for (int i = 0; i < 16; i++) {
    for (int j = 0; j < 8; j++) {
      archivoS.println(ROTvalue[i][j]);
    }
  }
  archivoS.close();

}

////////////////////////////////////////////////////////////////////////////////////////////
////////////////////////////////////////////////////////////////////////////////////////////

//////////////////////////////  S E T U P  //////////////////////////////
void setup() {
  btStop();
  // Serial
  Serial.begin(115200);
  // MISI USB
//  MIDI.begin(MIDI_CHANNEL_OMNI);
//  MIDI.setHandleNoteOn(handleNoteOn);  
//  MIDI.setHandleControlChange(handleCC);
//  // check device mounted
//  if ( !TinyUSBDevice.mounted() ){
//    Serial.println("Error USB");
//  }
  
  // Synth
  synthESP32_begin();
  // Set 16 voices
  for (byte f=0;f<16;f++){
    setSound(f);
  }
  // Set master vol
  synthESP32_setMVol(master_vol);
  // Set master filter
  synthESP32_setMFilter(master_filter);  


  
  // SPIFFS
  if (!SPIFFS.begin(true)) {
    Serial.println("Error al montar el sistema de archivos SPIFFS");
    return;
  } 
  
  // Leds
  strip.begin();
  strip.clear();           
  strip.show();            
  strip.setBrightness(50);
  // Seq


   // fill melodic with 60
  for  (byte a=0;a<16;a++){
    for  (byte b=0;b<16;b++){
     melodic[a][b]=60;
    }    
  }
  // set 8-15 as melodic;
  isMelodic=B11111111<<8 | B00000000;
  // Setup our clock system
  uClock.init();
  //uClock.setOnStep(onStepCallback);
  uClock.setOnSync24(onSync24Callback);
  uClock.setTempo(bpm);

//    // demo pattern
//    pattern[0]=B00010001<<8 | B10010001;
//    pattern[2]=B11000101<<8 | B10101011;
//    pattern[6]=B10110101<<8 | B10001111;
//    pattern[3]=B00000110<<8 | B00000000;
//    pattern[7]=B00000000<<8 | B01001000;
//    // start playing demo pattern
//    uClock.start();
//    sstep=firstStep;
//    refreshSTEP=true; 
//    playing=true;

  // Oled
  u8g2.begin();
  // Rotary
  pinMode(pinR1A,INPUT_PULLUP);
  pinMode(pinR1B,INPUT_PULLUP);
  pinMode(pinBR1,INPUT_PULLUP);
  attachInterrupt(pinR1A, i_ENCODERS, CHANGE);  
  attachInterrupt(pinR1B, i_ENCODERS, CHANGE);  
}

//////////////////////////////  L O O P  //////////////////////////////

void loop() {

  // flag to do things outside sequencer timer isr
  if (load_flag){
    load_flag=false;

    pattern_song_counter++;
    if (pattern_song_counter==255) pattern_song_counter=0;
    if (pattern_song_counter>last_pattern_song) pattern_song_counter=0; 
        
    load_pattern(song[pattern_song_counter]);
    selected_pattern=song[pattern_song_counter];
    load_sound(song[pattern_song_counter]);
    selected_sndSet=song[pattern_song_counter];
           
    refreshOLED=true;
  }

  // Read MIDI ports
  //MIDI.read();

  shiftR1=!digitalRead(pinBR1);
  READ_ENCODERS(); 
  READ_KEYPAD(); 
  DO_KEYPAD();
  REFRESH_LEDS();
  REFRESH_OLED();
  REFRESH_VUMETER();


}

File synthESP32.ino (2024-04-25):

void synthESP32_begin(){

  lpfL.setResonance(reso);
  lpfR.setResonance(reso);
 
  lpfL.setCutoffFreq(cutoff);
  lpfR.setCutoffFreq(cutoff); 
  
  lpf0.setResonance(reso);
  lpf1.setResonance(reso);
  lpf2.setResonance(reso);
  lpf3.setResonance(reso);
  lpf4.setResonance(reso);
  lpf5.setResonance(reso);
  lpf6.setResonance(reso);
  lpf7.setResonance(reso);
  lpf8.setResonance(reso);
  lpf9.setResonance(reso);
  lpf10.setResonance(reso);
  lpf11.setResonance(reso);
  lpf12.setResonance(reso);
  lpf13.setResonance(reso);
  lpf14.setResonance(reso);
  lpf15.setResonance(reso);
  lpf0.setCutoffFreq(cutoff);
  lpf1.setCutoffFreq(cutoff);
  lpf2.setCutoffFreq(cutoff);
  lpf3.setCutoffFreq(cutoff);
  lpf4.setCutoffFreq(cutoff);
  lpf5.setCutoffFreq(cutoff);
  lpf6.setCutoffFreq(cutoff);
  lpf7.setCutoffFreq(cutoff);
  lpf8.setCutoffFreq(cutoff);
  lpf9.setCutoffFreq(cutoff);
  lpf10.setCutoffFreq(cutoff);
  lpf11.setCutoffFreq(cutoff);
  lpf12.setCutoffFreq(cutoff);
  lpf13.setCutoffFreq(cutoff);
  lpf14.setCutoffFreq(cutoff);
  lpf15.setCutoffFreq(cutoff);
      
  i2s_config_t i2s_config = {
    .mode = (i2s_mode_t)(I2S_MODE_MASTER | I2S_MODE_TX ),
    .sample_rate = SAMPLE_RATE,
    .bits_per_sample = I2S_BITS_PER_SAMPLE_16BIT,
    .channel_format = I2S_CHANNEL_FMT_RIGHT_LEFT,
    .communication_format = (i2s_comm_format_t)(I2S_COMM_FORMAT_I2S | I2S_COMM_FORMAT_I2S_MSB),
    //.communication_format = (i2s_comm_format_t)(I2S_COMM_FORMAT_I2S | I2S_COMM_FORMAT_I2S_LSB),
    .intr_alloc_flags = ESP_INTR_FLAG_LEVEL2,
    .dma_buf_count = DMA_NUM_BUF,
    .dma_buf_len = DMA_BUF_LEN,
    .use_apll = true,
  };

  i2s_pin_config_t i2s_pin_config = {
    .bck_io_num = I2S_BCK_PIN,
    .ws_io_num =  I2S_WS_PIN,
    .data_out_num = I2S_DATA_OUT_PIN
  };


  i2s_driver_install(I2S_NUM_0, &i2s_config, 0, NULL);

  i2s_set_pin(I2S_NUM_0, &i2s_pin_config);
  //i2s_zero_dma_buffer(I2S_NUM_0);


    // Highest possible priority for realtime audio task
    xTaskCreate(audio_task, "audio", 8000, NULL, configMAX_PRIORITIES - 1, NULL); 
}
static void write_buffer() {
	
	size_t bytes_written;

  for (int i=0; i < DMA_BUF_LEN; i++) {
	
	
  //-------------------------------
  // Time division
  //-------------------------------
  divider++;
  if (divider>=16) divider=0;
  
  //-------------------------------
  // Volume envelope generator
  //-------------------------------

   if (!(((unsigned char*)&EPCW[divider])[1]&0x80)) {
   AMP[divider] = wenvs[envs[divider]][ (((unsigned char*)&(EPCW[divider]+=EFTW[divider]))[1])];

	
  } else {
    AMP[divider] = 0;
  }
  
	
  //-------------------------------
  //  Synthesizer/audio mixer
  //-------------------------------

	// Generate sounds
	
	int32_t sound_A[16];
 
	sound_A[0]=(((signed char)(wtables[wavs[0] ][((unsigned char *)&(PCW[0]  += FTW[0] ))[1]]) * AMP[0]   ) >> 8);
	sound_A[1]=(((signed char)(wtables[wavs[1] ][((unsigned char *)&(PCW[1]  += FTW[1] ))[1]]) * AMP[1]   ) >> 8);
	sound_A[2]=(((signed char)(wtables[wavs[2] ][((unsigned char *)&(PCW[2]  += FTW[2] ))[1]]) * AMP[2]   ) >> 8);
	sound_A[3]=(((signed char)(wtables[wavs[3] ][((unsigned char *)&(PCW[3]  += FTW[3] ))[1]]) * AMP[3]   ) >> 8);
	sound_A[4]=(((signed char)(wtables[wavs[4] ][((unsigned char *)&(PCW[4]  += FTW[4] ))[1]]) * AMP[4]   ) >> 8);
	sound_A[5]=(((signed char)(wtables[wavs[5] ][((unsigned char *)&(PCW[5]  += FTW[5] ))[1]]) * AMP[5]   ) >> 8);
	sound_A[6]=(((signed char)(wtables[wavs[6] ][((unsigned char *)&(PCW[6]  += FTW[6] ))[1]]) * AMP[6]   ) >> 8);	
	sound_A[7]=(((signed char)(wtables[wavs[7] ][((unsigned char *)&(PCW[7]  += FTW[7] ))[1]]) * AMP[7]   ) >> 8);	
	sound_A[8]=(((signed char)(wtables[wavs[8] ][((unsigned char *)&(PCW[8]  += FTW[8] ))[1]]) * AMP[8]   ) >> 8);	
	sound_A[9]=(((signed char)(wtables[wavs[9] ][((unsigned char *)&(PCW[9]  += FTW[9] ))[1]]) * AMP[9]   ) >> 8);	
	sound_A[10]=(((signed char)(wtables[wavs[10] ][((unsigned char *)&(PCW[10]  += FTW[10] ))[1]]) * AMP[10]   ) >> 8);
	sound_A[11]=(((signed char)(wtables[wavs[11] ][((unsigned char *)&(PCW[11]  += FTW[11] ))[1]]) * AMP[11]   ) >> 8);
	sound_A[12]=(((signed char)(wtables[wavs[12] ][((unsigned char *)&(PCW[12]  += FTW[12] ))[1]]) * AMP[12]   ) >> 8);
	sound_A[13]=(((signed char)(wtables[wavs[13] ][((unsigned char *)&(PCW[13]  += FTW[13] ))[1]]) * AMP[13]   ) >> 8);
	sound_A[14]=(((signed char)(wtables[wavs[14] ][((unsigned char *)&(PCW[14]  += FTW[14] ))[1]]) * AMP[14]   ) >> 8);
	sound_A[15]=(((signed char)(wtables[wavs[15] ][((unsigned char *)&(PCW[15]  += FTW[15] ))[1]]) * AMP[15]   ) >> 8);


  //taskYIELD(); 
  
  // tracks filter
  sound_A[0]=lpf0.next(sound_A[0])<<0;
  sound_A[1]=lpf1.next(sound_A[1])<<0;
  sound_A[2]=lpf2.next(sound_A[2])<<0;
  sound_A[3]=lpf3.next(sound_A[3])<<0;
  sound_A[4]=lpf4.next(sound_A[4])<<0;
  sound_A[5]=lpf5.next(sound_A[5])<<0;
  sound_A[6]=lpf6.next(sound_A[6])<<0;
  sound_A[7]=lpf7.next(sound_A[7])<<0;
  sound_A[8]=lpf8.next(sound_A[8])<<0;
  sound_A[9]=lpf9.next(sound_A[9])<<0;
  sound_A[10]=lpf10.next(sound_A[10])<<0;
  sound_A[11]=lpf11.next(sound_A[11])<<0;
  sound_A[12]=lpf12.next(sound_A[12])<<0;
  sound_A[13]=lpf13.next(sound_A[13])<<0;
  sound_A[14]=lpf14.next(sound_A[14])<<0;
  sound_A[15]=lpf15.next(sound_A[15])<<0;

  taskYIELD(); 
  
	// L & R outputs
	
	int32_t loutput= 127 +
	((
	((sound_A[0] * VOL_L[0]   ) >> 3 )+
	((sound_A[1] * VOL_L[1]   ) >> 3 )+
	((sound_A[2] * VOL_L[2]   ) >> 3 )+
	((sound_A[3] * VOL_L[3]   ) >> 3 )+
	((sound_A[4] * VOL_L[4]   ) >> 3 )+
	((sound_A[5] * VOL_L[5]   ) >> 3 )+
	((sound_A[6] * VOL_L[6]   ) >> 3 )+
	((sound_A[7] * VOL_L[7]   ) >> 3 )+
	((sound_A[8] * VOL_L[8]   ) >> 3 )+
	((sound_A[9] * VOL_L[9]   ) >> 3 )+
	((sound_A[10]* VOL_L[10]  ) >> 3 )+
	((sound_A[11]* VOL_L[11]  ) >> 3 )+
	((sound_A[12]* VOL_L[12]  ) >> 3 )+
	((sound_A[13]* VOL_L[13]  ) >> 3 )+
	((sound_A[14]* VOL_L[14]  ) >> 3 )+
	((sound_A[15]* VOL_L[15]  ) >> 3 ) 
    ) >> 3);

  //loutput += delay1.next(loutput)>>1;
	
	int32_t routput= 127 +
	((
	((sound_A[0] * VOL_R[0]   ) >> 3 )+
	((sound_A[1] * VOL_R[1]   ) >> 3 )+
	((sound_A[2] * VOL_R[2]   ) >> 3 )+
	((sound_A[3] * VOL_R[3]   ) >> 3 )+
	((sound_A[4] * VOL_R[4]   ) >> 3 )+
	((sound_A[5] * VOL_R[5]   ) >> 3 )+
	((sound_A[6] * VOL_R[6]   ) >> 3 )+
	((sound_A[7] * VOL_R[7]   ) >> 3 )+
	((sound_A[8] * VOL_R[8]   ) >> 3 )+
	((sound_A[9] * VOL_R[9]   ) >> 3 )+
	((sound_A[10]* VOL_R[10]  ) >> 3 )+
	((sound_A[11]* VOL_R[11]  ) >> 3 )+
	((sound_A[12]* VOL_R[12]  ) >> 3 )+
	((sound_A[13]* VOL_R[13]  ) >> 3 )+
	((sound_A[14]* VOL_R[14]  ) >> 3 )+
	((sound_A[15]* VOL_R[15]  ) >> 3 ) 
    ) >> 3); 
  
	uint8_t lrefilter=lpfL.next(loutput)<<0;
	uint8_t rrefilter=lpfR.next(routput)<<0;
	
	int16_t lsample_out=(lrefilter*mvol)>>5;
	int16_t rsample_out=(rrefilter*mvol)>>5;	
  
	if (lsample_out>250) lsample_out=250;
	if (rsample_out>250) rsample_out=250;

  out_buf[i*2]   = (uint16_t)lsample_out<<8;  
  out_buf[i*2+1] = (uint16_t)rsample_out<<8;
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
